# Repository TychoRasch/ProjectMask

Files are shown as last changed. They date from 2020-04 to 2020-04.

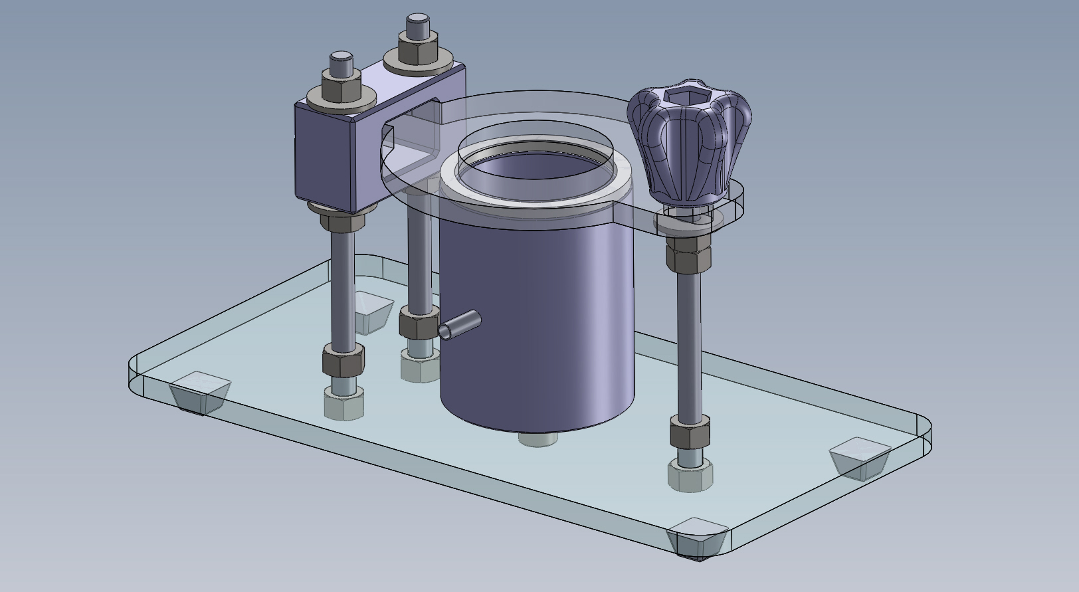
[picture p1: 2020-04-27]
src/04 Dry Particle Test/Particle test v1.1/Assembly.JPG

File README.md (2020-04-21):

---
title: ProjectMask
description: Open-source face mask testing equipment  
keywords:
- covid-19
- sars-cov-2
- respirator
- face-mask
- protection 
- medical equipment 
- testing 
- particle penetration 
- pressure drop
- carbon dioxide buildup
- FIT test
- safety
project-link: https://www.projectmask.nl/
intended use: >- 
made: true
made-independently: false
license:
  hardware: undefined
okh-manifest-version: 1.0.0
date-updated: 2020-03-30
version: v.1.0.0
manifest-author:
  name: ProjectMask 
  affiliation: Delft University of Technology
contributors:
  - John van den Dobbelsteen
  - Stefan Lampaert
  - Johan Brans
  - Stefan van den Toorn
  - Tycho Rasch
  - Thijs Blad
  - Freek Broeren
  - Joep Nijssen
  - Nick White
  - Erik van de Wetering
  - Kylian van Puffelen
  - Joeri Roos
  - Stefan Molenaar
  - Max Wouters
  - Robin Bastiaanse
  - Rutger Ham
  - Joshua Spaander
  - Martijn Suurveld
sub-parts:
  - Breathing Resistance Test
  - Carbon Dioxide Test
  - Dry Particle Penetration Test
  - Filter Material Penetration Test
  - FIT Test
location:
  - Delft, the Netherlands
  
---
  
  # Title: ProjectMask: Open-source face mask testing equipment
  
  ## Introduction

  With the onset of the COVID-19 pandemic, the production of face masks has increased manyfold. The increase in production has also increased the need for testing facilities to test masks. Masks must be tested to ensure they meet their given specification to protect healthcare workers. 

  ProjectMask of the Delft University of Technology was established to develop testing equipment to be able to perform testing on face masks. ProjectMask aims to make the information publicly available to increase the capacity of testing equipment. 
    
  ### Reference: 
  
  All the info compiled here can be found [in this link](https://projectmask.nl/)

  ### General considerations before starting
  
  #### Mask certification
  
  - ProjectMask and the Delft University of Technology are no certifying bodies which means that we cannot say that certain masks are safe to be used. We merely aim to provide information regarding the tests, testing setup and procedures.

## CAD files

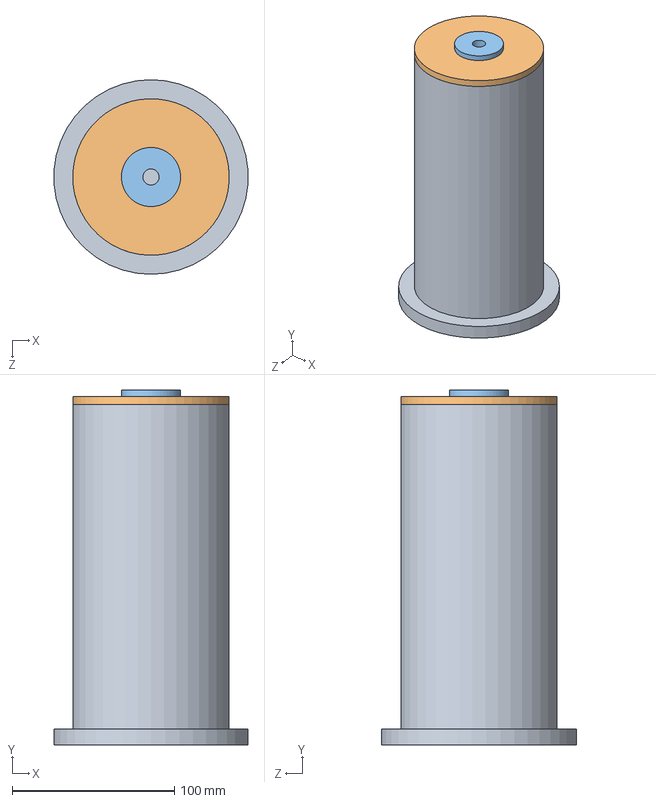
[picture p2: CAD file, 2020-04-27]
src/04 Dry Particle Test/Nebulizer/SolidworksNEN/Assembly Atomizer.SLDASM
119.7 x 219.0 x 120.0 mm
Base
Cover
Bush

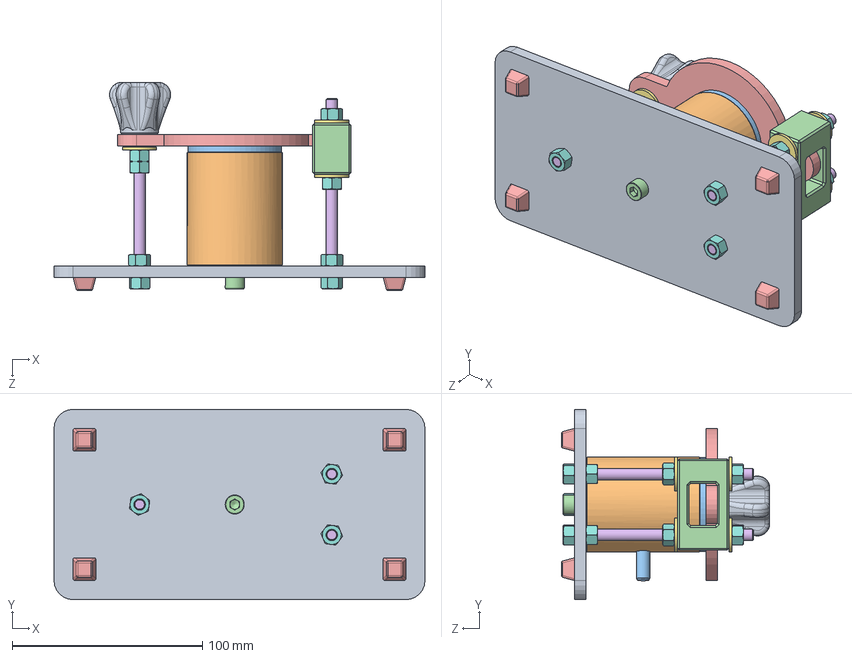
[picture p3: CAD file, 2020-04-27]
src/04 Dry Particle Test/Particle test v1.1/Solidworks model/Assembly.SLDASM
195.0 x 100.0 x 109.5 mm
Baseplate v2
Particle chamber v3
Seal ring
Lid container v3
Compression lid v2
M6x100 rod x 3
plain washer large_din x 5
hex nut gradec_din x 12
Knob M6
hex nut gradec_iso x 2
Pipe
socket head cap screw_iso
Rubber foot x 4

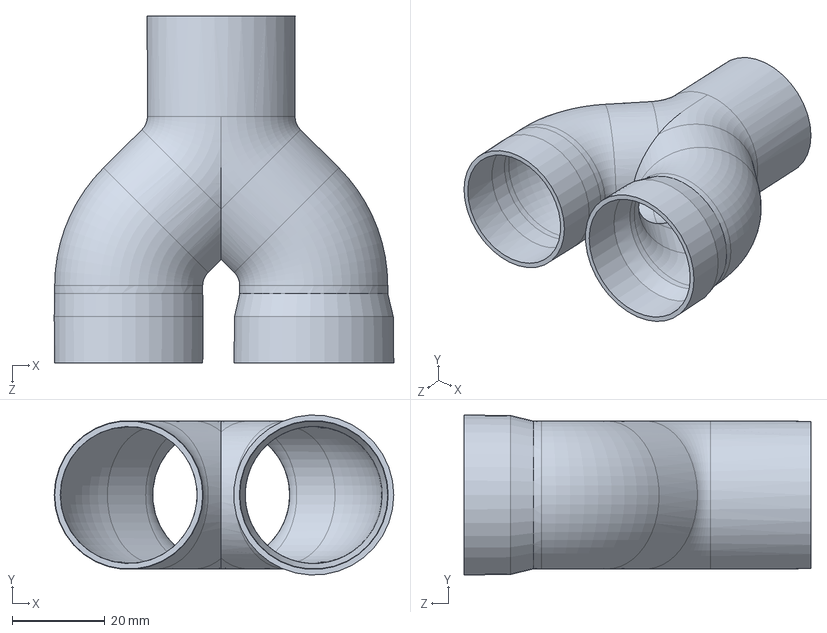
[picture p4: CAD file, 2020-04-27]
src/03 Carbon Dioxide Test/Parts/PARTAftakking_Assembly.SLDPRT
73.4 x 34.6 x 75.0 mm

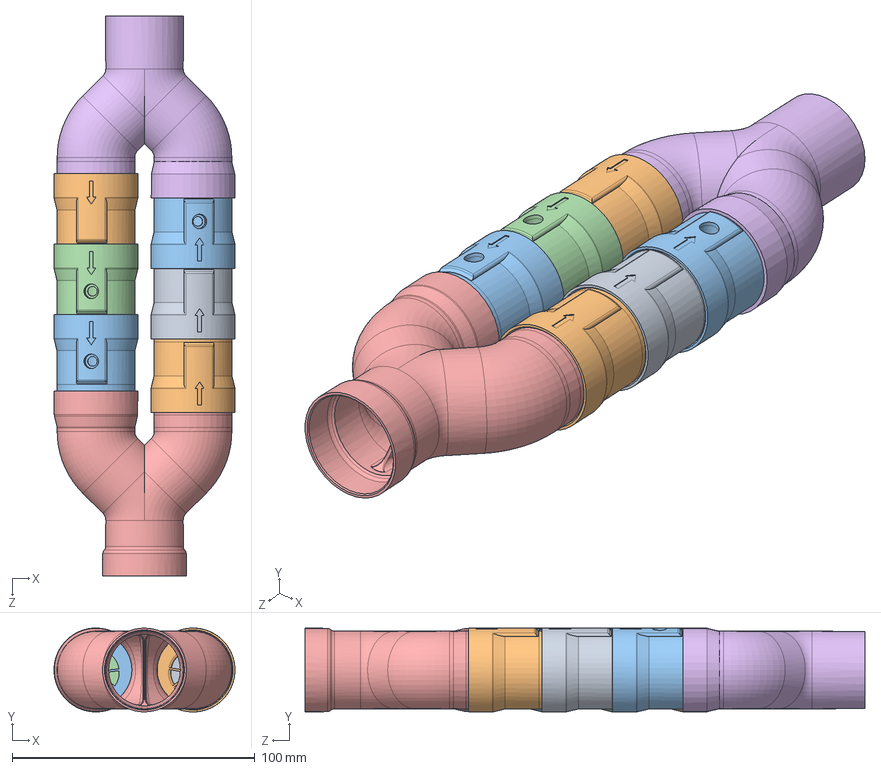
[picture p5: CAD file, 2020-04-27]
src/03 Carbon Dioxide Test/Parts/PARTPipingWithOneWayValves.SLDASM
74.6 x 34.6 x 230.7 mm
PARTAftakking_Assembly
PARTMerging_Assembly
PARTRestrictie_metGat_Assembly
PARTOneWayValve_Assembly x 2
PARTOneWayValve_zonderGat_Assembly x 2
PARTRestrictie_zonderGat_Assembly

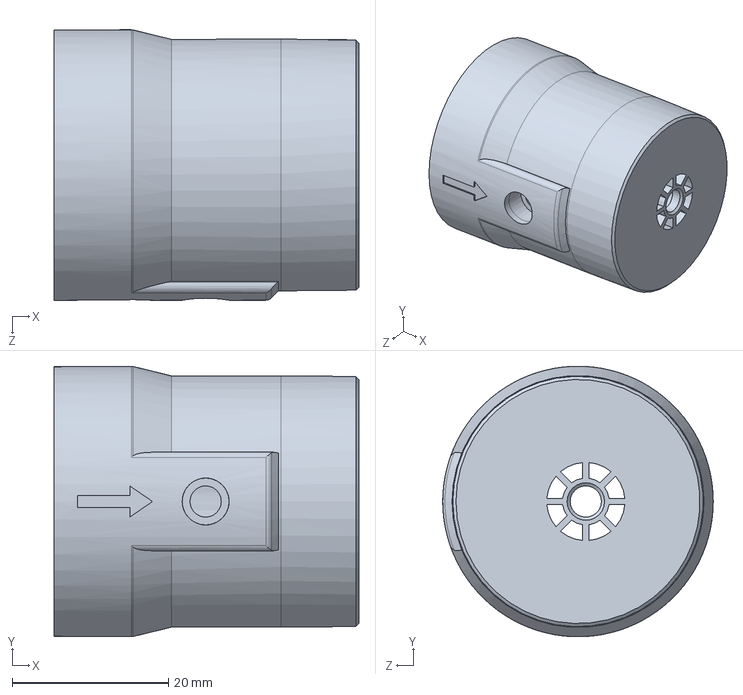
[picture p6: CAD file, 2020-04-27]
src/03 Carbon Dioxide Test/Parts/PARTRestrictie_metGat_Assembly.SLDPRT
39.0 x 34.6 x 34.6 mm

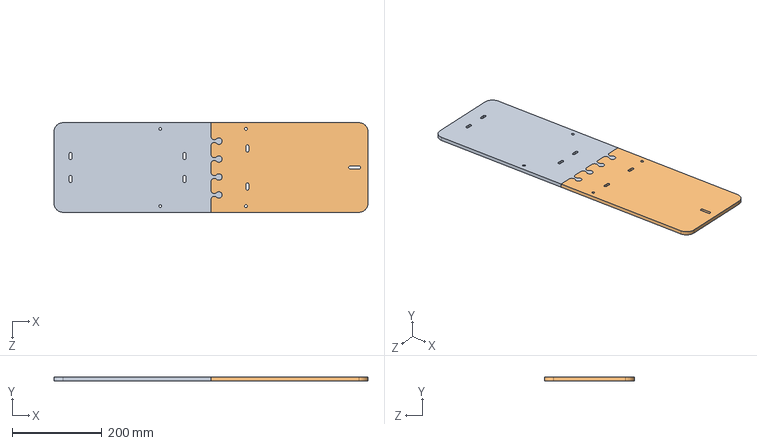
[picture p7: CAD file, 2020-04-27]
src/03 Carbon Dioxide Test/Parts/PARTBuildPlate.SLDASM
700.0 x 8.00 x 200.0 mm
Baseplate_versie1.3_Links.step
Baseplate_versie1.3_Rechts.step

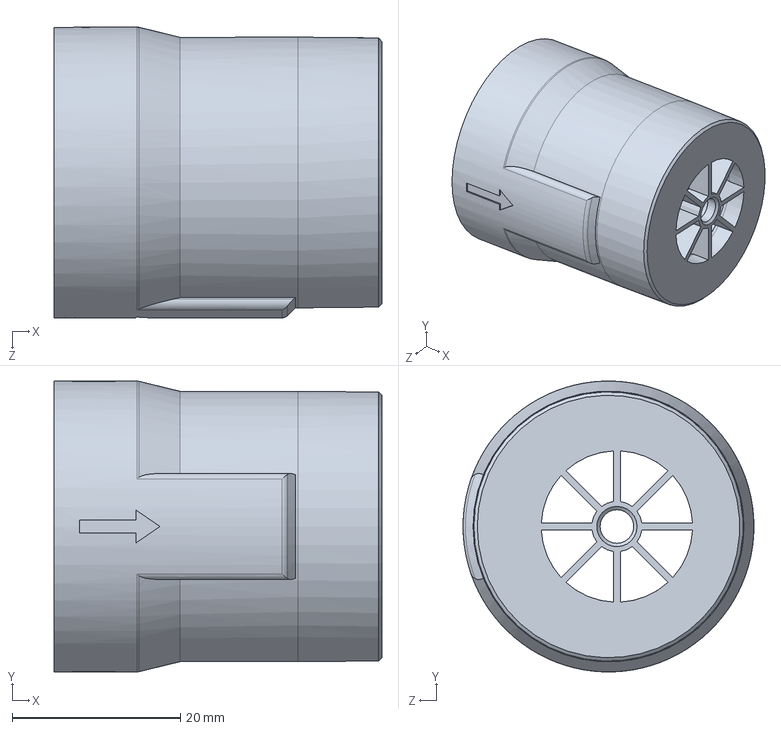
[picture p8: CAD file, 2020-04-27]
src/03 Carbon Dioxide Test/Parts/PARTOneWayValve_zonderGat_Assembly.SLDPRT
39.0 x 34.6 x 34.6 mm

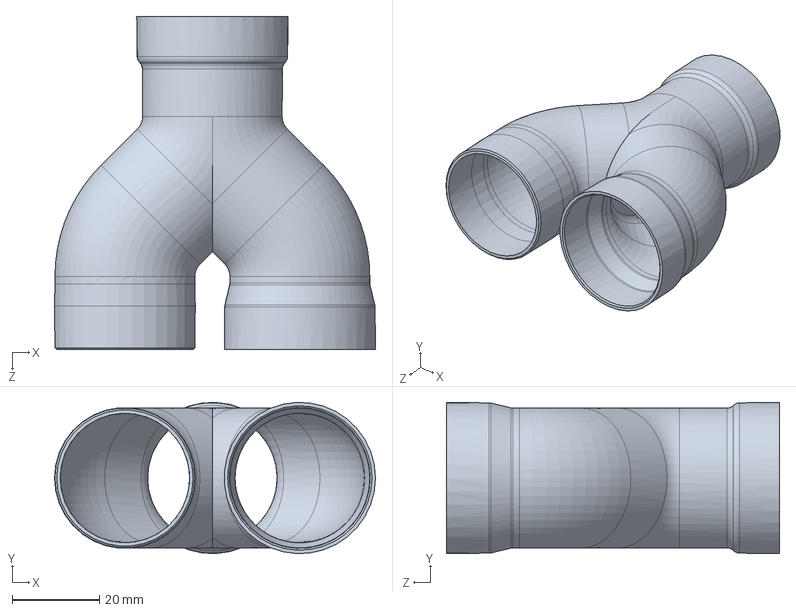
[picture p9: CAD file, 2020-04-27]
src/03 Carbon Dioxide Test/Parts/PARTMerging_Assembly.SLDPRT
73.4 x 34.6 x 76.2 mm

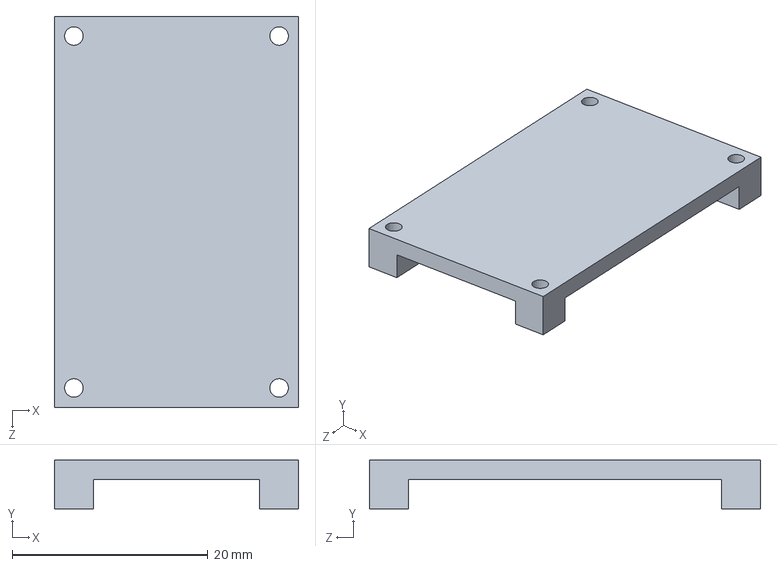
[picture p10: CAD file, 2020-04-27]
src/03 Carbon Dioxide Test/Parts/PARTSensorMounts.SLDPRT
25.0 x 5.00 x 40.0 mm

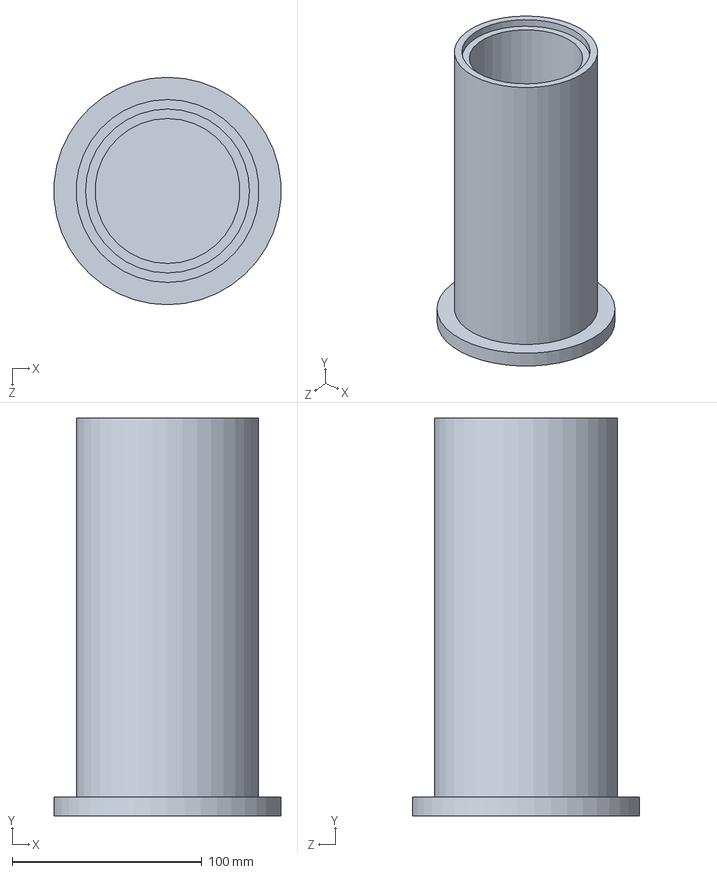
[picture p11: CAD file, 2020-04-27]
src/04 Dry Particle Test/Nebulizer/SolidworksNEN/Base.SLDPRT
119.7 x 210.0 x 120.0 mm

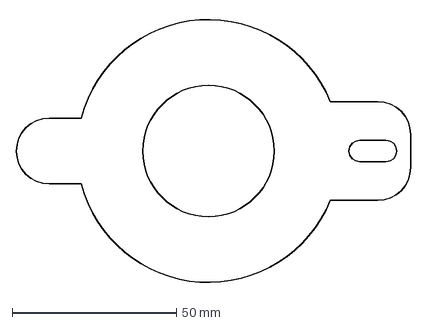
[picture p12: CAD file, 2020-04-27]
src/04 Dry Particle Test/Particle test v1.1/Laser cut files/Compression lid v2.DXF
120.0 x 82.1 mm

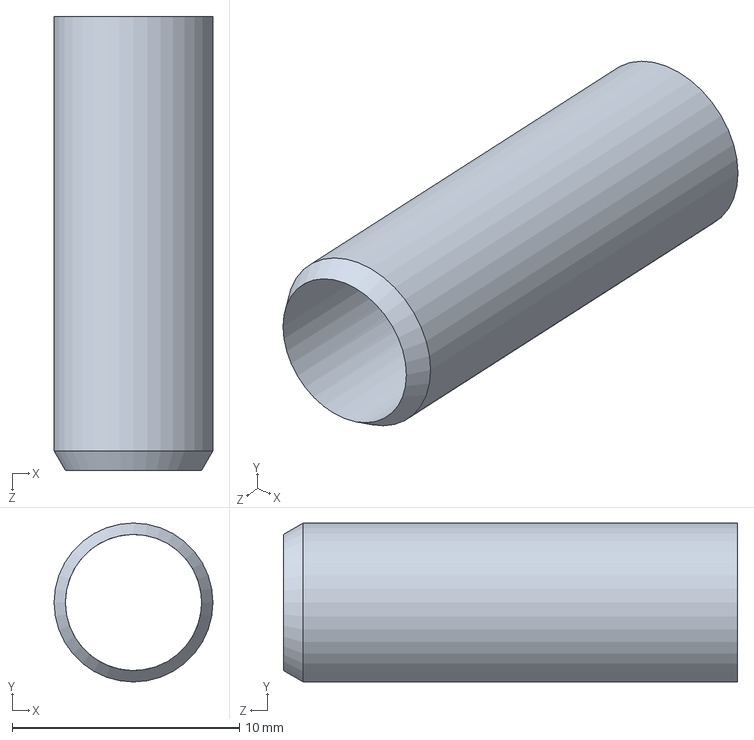
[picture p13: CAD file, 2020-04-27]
src/04 Dry Particle Test/Particle test v1.1/Solidworks model/Pipe.SLDPRT
7.00 x 7.00 x 20.0 mm

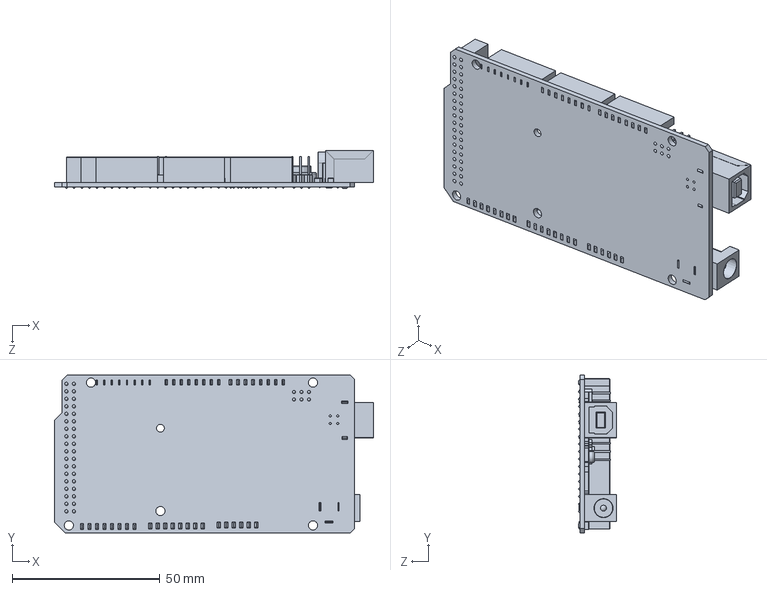
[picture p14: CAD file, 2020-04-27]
src/03 Carbon Dioxide Test/Parts/ArduinoMega.SLDPRT
107.9 x 53.4 x 13.0 mm

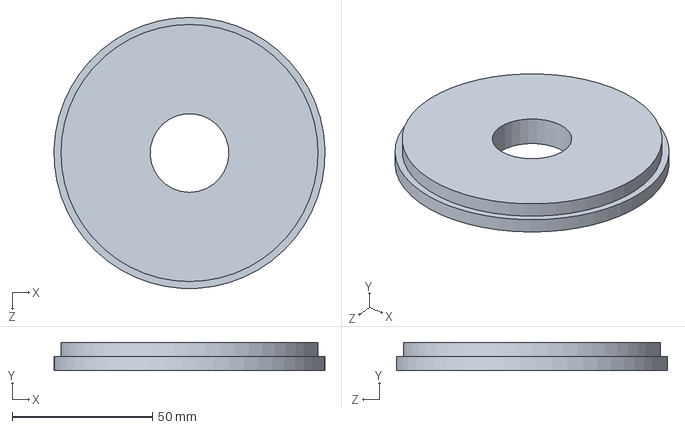
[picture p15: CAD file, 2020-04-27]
src/04 Dry Particle Test/Nebulizer/SolidworksNEN/Cover.SLDPRT
96.5 x 10.0 x 96.5 mm

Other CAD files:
src/03 Carbon Dioxide Test/Parts/PARTReservoirAssembly.SLDASM
src/03 Carbon Dioxide Test/Parts/PARTRestrictie_zonderGat_Assembly.SLDPRT
src/03 Carbon Dioxide Test/Parts/PARTVenturiAssembly.SLDASM
src/03 Carbon Dioxide Test/Parts/PARTOneWayValve_Assembly.SLDPRT
src/03 Carbon Dioxide Test/Parts/Arduino_Mega_Mount.SLDPRT
src/03 Carbon Dioxide Test/Parts/Arduino_Mega_MountV2.SLDPRT
src/03 Carbon Dioxide Test/Parts/PART16mm Tube Connect Venturi.SLDPRT
src/03 Carbon Dioxide Test/Parts/PART16mm buis Venturi.SLDPRT
src/03 Carbon Dioxide Test/Parts/PART32-16mm buis Venturi.SLDPRT
src/03 Carbon Dioxide Test/Parts/PART32mm Tube Connect Venturi.SLDPRT
src/03 Carbon Dioxide Test/Parts/PART32mm buis Reservoir.SLDPRT
src/03 Carbon Dioxide Test/Parts/PART32mm buis TubeConnect.SLDPRT
src/03 Carbon Dioxide Test/Parts/PART32mm buis Venturi.SLDPRT
src/03 Carbon Dioxide Test/Parts/PART32mm buis.SLDPRT
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

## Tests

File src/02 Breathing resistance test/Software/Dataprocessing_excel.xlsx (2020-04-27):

 |  |  |  |  |  |  |  | Flow [L/min] | Pressure [Pa]
PWM: | 21 | flow sensor value | 511 | pressure sensor value | 506 | sensorpulstijd | 0 | 0.2474414585 | 0.09484477974
PWM: | 21 | flow sensor value | 513 | pressure sensor value | 507 | sensorpulstijd | 0 | 0.7423243755 | 0.06349113355
PWM: | 21 | flow sensor value | 509 | pressure sensor value | 507 | sensorpulstijd | 0 | 1.237207292 | 0.06349113355
PWM: | 21 | flow sensor value | 508 | pressure sensor value | 511 | sensorpulstijd | 0 | 1.732090209 | 0.0007838411549
PWM: | 21 | flow sensor value | 507 | pressure sensor value | 516 | sensorpulstijd | 0 | 2.226973126 | 0.06349113355
PWM: | 21 | flow sensor value | 508 | pressure sensor value | 515 | sensorpulstijd | 0 | 1.732090209 | 0.03840821659
PWM: | 21 | flow sensor value | 509 | pressure sensor value | 511 | sensorpulstijd | 0 | 1.237207292 | 0.0007838411549
PWM: | 22 | flow sensor value | 508 | pressure sensor value | 510 | sensorpulstijd | 0 | 1.732090209 | 0.007054570394
PWM: | 22 | flow sensor value | 509 | pressure sensor value | 506 | sensorpulstijd | 0 | 1.237207292 | 0.09484477974
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

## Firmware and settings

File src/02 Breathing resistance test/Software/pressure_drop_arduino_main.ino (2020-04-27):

// Initialize all the pins and constants
#define flowPin         A1  // pin A1 is being used for the pressure sensor to determine the flow
#define pressurePin     A0  // pin A2 is being used for the pressure sensor to determine the pressure drop
#define fanPWMpin       3  // Pin D3 is being used to send the PWM signal to the fan, this is the brown cable
#define fanSensor       8  // Pin D8 is being used for the tachograph of the fan, this is the yellow cable
#define relaisPin       7  // Pin D7 is being used for the safety relais (too high pressure value will switch of fan)
#define pres_modePin    12 // Pin D12 determines which mode is being used for the pressure sensor (HIGH or LOW) for (Nonlin or lin) respectively
#define flow_modePin    13 // Pin D13 determines which mode is being used for the flow pressure sensor (HIGH or LOW) for (Nonlin or lin) respectively
#define max_sensor_val  910 // max value for the sensor where it will not be damaged
#define Puls            4  // Number of pulses from the fan for the PWM signal, 4 pulses is 1 rotations
#define n_samples       10 // Number of samples per PWM value
#define PWM_min         20  // min PWM value (this can be set when the fan only starts spinning at higher PWM values)
#define PWM_max         255 // max PWM value
#define pressure_nonlin true // TRUE is nonlin mode for the pressure sensor, FALSE is lin mode for the pressure sensor
#define flow_nonlin     true // TRUE is nonlin mode for the flow pressure sensor, FALSE is lin mode for the flow pressure sensor

// initialize all variables
int measured_flow       = 0;  // measured value for the flow [0-1023]
int measured_pressure   = 0;  // measured value for the pressure [0-1023]
bool safety_switch      = true; // safety switch, true if the measurement can continue, false is it is not safe to do so
int i_PWM               = PWM_min;  // i value for PWM sweep
int i_measurement       = 0;  // i for in the measurement
unsigned long SensorPulsTime; //

// set the mode for the pressure sensors nonlin is better accuracy around the zero point of the sensor
void setpressureSensors() {
  if (pressure_nonlin ==  true){
    digitalWrite(pres_modePin,HIGH);
  }
  else {
    digitalWrite(pres_modePin,LOW);
  }

  if (flow_nonlin ==  true){
    digitalWrite(flow_modePin,HIGH);
  }
  else {
    digitalWrite(flow_modePin,LOW);
  }
}


void setup() {
  Serial.begin(9600);
  pinMode(fanSensor, INPUT);
  pinMode(relaisPin, OUTPUT);
  pinMode(pres_modePin, OUTPUT);
  pinMode(flow_modePin, OUTPUT);
  digitalWrite(fanSensor,HIGH);
  digitalWrite(relaisPin, HIGH);

  setpressureSensors();
}

void loop() {
  // Run the script for the lowest PWM value, this script will only start when
  // the Serial monitor is avalible (also open the relais port)
  if (i_PWM==PWM_min){
    if (Serial.available()){
      analogWrite(fanPWMpin, i_PWM);
      digitalWrite(relaisPin, LOW);
      delay(1000);
      i_PWM++;
      Serial.println("Nieuwe meting gestart");
    }
  }

  // Run the script for different PWM values
  if (i_PWM>PWM_min && i_PWM<PWM_max){
    i_PWM = do_measurement(i_PWM);
  }

  // when the script is completed end the serial line and print end statement
  if (i_PWM==PWM_max){
    analogWrite(fanPWMpin, 0);
    digitalWrite(relaisPin, HIGH);
    Serial.println("end");
    Serial.end();
    i_PWM++;
  }

}

// Doing the measurement
int do_measurement(int i_PWM){
  analogWrite(fanPWMpin, i_PWM);          //write the analog value to the fan

  // printing the measurement 10 times the serial port for each PWM value (to 
  // settle the system)
  for (int i_measurement=0 && i_PWM!=PWM_max; i_measurement < 10; i_measurement++) {
    // measure the flow pressure and pressure drop, these are non processed 
    // values and dependent of the type of sensor
    measured_flow = analogRead(flowPin);
    measured_pressure = analogRead(pressurePin);
    SensorPulsTime = pulseIn(fanSensor, LOW, 300000);

    // print the values to the Serial monitor
    Serial.print("PWM: ,");
    Serial.print(i_PWM);
    Serial.print(", flow sensor value ,");
    Serial.print(measured_flow);
    Serial.print(", pressure sensor value ,");
    Serial.print(measured_pressure);
    Serial.print(", SensorPulsTime ,");
    Serial.println(SensorPulsTime);

    // safety switch, if the sensor is overloaded the system will shut down and 
    // stop measurement to prevent damage to the sensors.
    if (measured_pressure>max_sensor_val or measured_flow>max_sensor_val){
      digitalWrite(relaisPin, HIGH);
      i_measurement = 11;
      safety_switch = false;
      i_PWM = PWM_max;
      Serial.println("end");
      Serial.end();
      break;
    }
    // delay for the system to settle, this is 100 ms, minus the time which has 
    // elapsed to find the sensor pulse time
    delayMicroseconds(100e3-SensorPulsTime);
  }

  // increase and return PWM value to the main script 
  i_PWM++;
  return i_PWM;
}

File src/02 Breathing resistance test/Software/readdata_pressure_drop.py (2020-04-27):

##############
## Script listens to serial port and writes contents into a file
##############
## requires pySerial and datetime to be installed 
import serial
import datetime
import time

# Determine which serial is connected
import serial.tools.list_ports
comlist = serial.tools.list_ports.comports()
connected = []
i = 0
for element in comlist:
    connected.append(element.device)

# List the different com ports which are in use
for x in connected:
	print("[",i,"]"," ", x)
	i=i+1

# Prompt user for which arduino is connected
i = int(input("Which com port do you wish to use?: "))
serial_port = connected[i]

# Prompt user for which setup is being used
#i = int(input("Which setup are you using?: "))
#setup_type = "setup_%d" % i

# Prompt user for which sample is being used
sample_number = str(input("Which sample are you using?: "))
#sample_number = "sample_%s" % str(i).zfill(3)

# Create a timestamp for the output name of the file
x = datetime.datetime.now()

# Create a filename to which the file is being saved
name =  "./data/resistance_%s_%d_%s_%s_%s_%s_%s.csv" % (sample_number, x.year, str(x.month).zfill(2), str(x.day).zfill(2), str(x.hour).zfill(2), str(x.minute).zfill(2), str(x.second).zfill(2))
write_to_file_path = name
output_file = open(write_to_file_path, "w+")

# Open the serial monitor and prompt the script to start the measurement
baud_rate = 9600 #In arduino, Serial.begin(baud_rate)
ser = serial.Serial(serial_port, baud_rate, timeout=5)
time.sleep(2)
ser.write(b"1")

# Let the arduino do the measurement and store data to csv file
while True:
    line = ser.readline();
    print(f"Binary: \"{line}\"")
    line = line.decode("utf-8") #ser.readline returns a binary, convert to string
    print(f"Decoded: \"{line}\"")
    output_file.write(line)
    if line.startswith("end"):
        print("Meting is afgelopen/ afgebroken")
        ser.close()
        break

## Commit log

2020-04-27 Source files upload
    Upload van alle source files en docs.
    [ArduinoMega.SLDPRT, Arduino_Mega_Mount.SLDPRT, Arduino_Mega_MountV2.SLDPRT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]
2020-04-27 Revert "Source files upload"
    This reverts commit 8d8cb68388bfa496b6a371433959bb1d050b5d8b.
    [ArduinoMega.SLDPRT, Arduino_Mega_Mount.SLDPRT, Arduino_Mega_MountV2.SLDPRT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]
2020-04-27 ProjectMask source files
    All source files to create the testing setup used by ProjectMask
    [ArduinoMega.SLDPRT, Arduino_Mega_Mount.SLDPRT, Arduino_Mega_MountV2.SLDPRT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]
